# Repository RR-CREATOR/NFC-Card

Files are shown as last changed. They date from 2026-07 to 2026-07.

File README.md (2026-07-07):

# RRcard

RRcard is my NFC business card / hacker card. It uses an NT3H2111 NFC chip with a PCB antenna, so tapping it with a phone can open my links without needing a QR code or typing anything manually.

I made this because normal business cards are kinda boring, and I wanted something that felt more like a PCB project than paper with text on it. I also wanted an excuse to KiCad, fight NFC antenna math, and see if I could get a tiny board fab-ready.

## Pictures

### Full 3D model

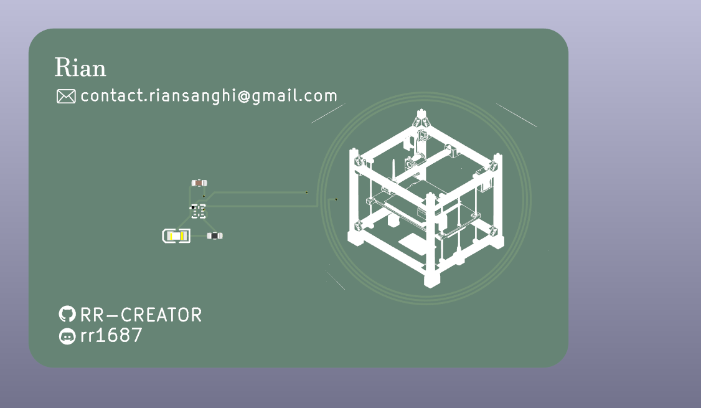
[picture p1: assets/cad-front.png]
Full 3D model front


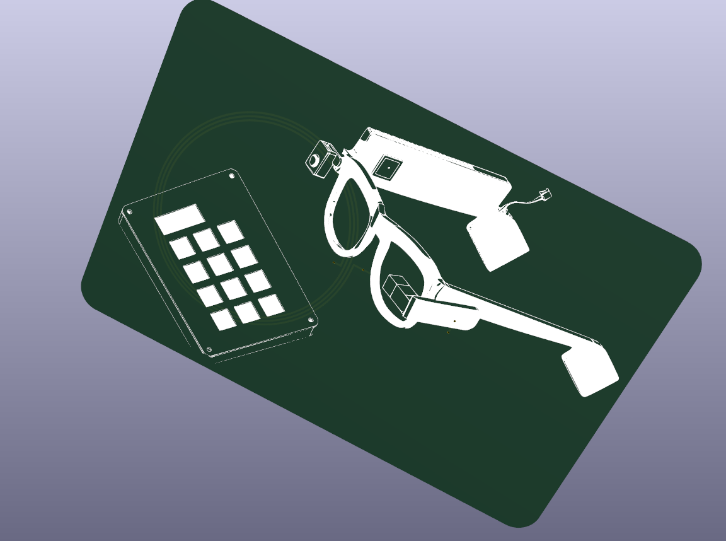
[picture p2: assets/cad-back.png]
Full 3D model back


### PCB

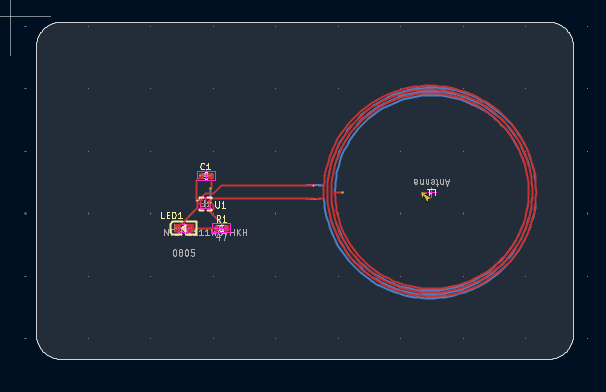
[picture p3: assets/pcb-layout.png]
PCB layout


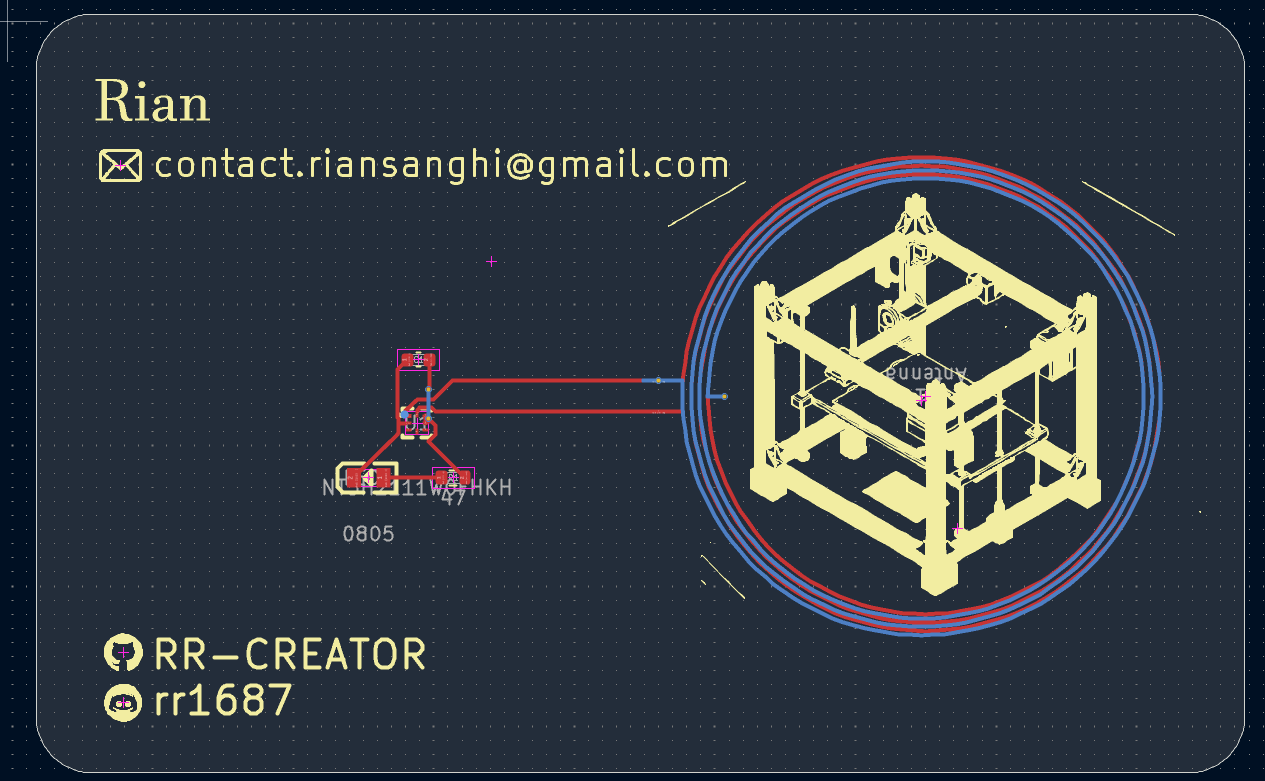
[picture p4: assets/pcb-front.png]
PCB front


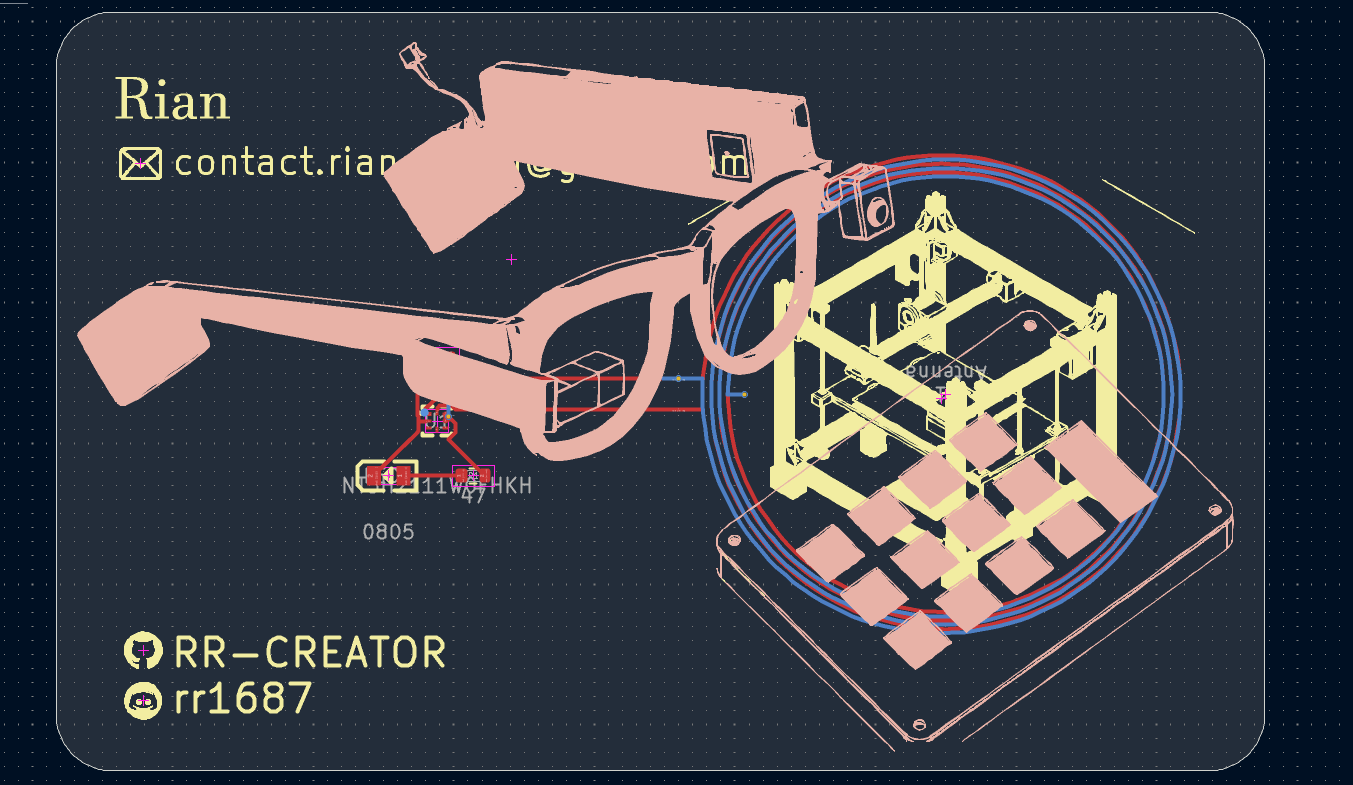
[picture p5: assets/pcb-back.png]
PCB back


### Schematic

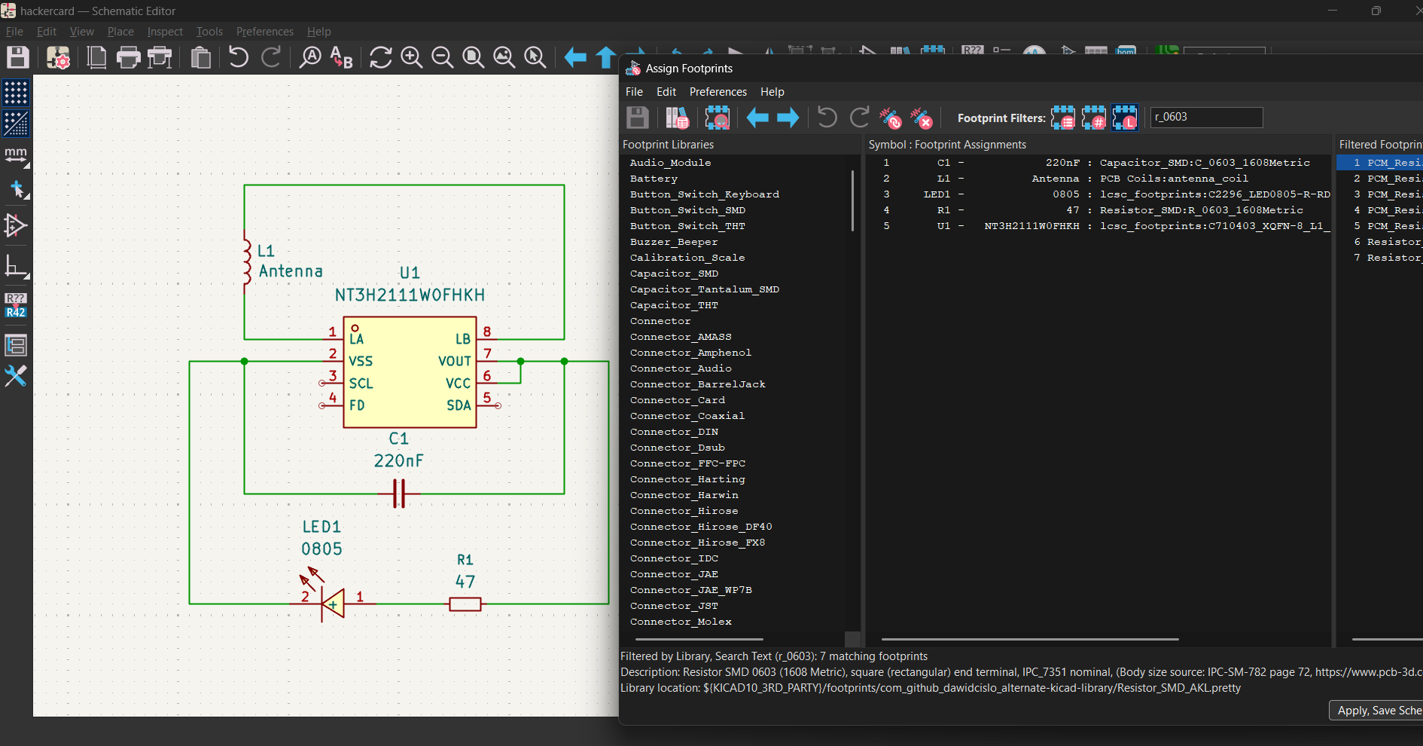
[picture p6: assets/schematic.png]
Schematic


## PCB design files

The KiCad files are in [`PCB design files`](PCB%20design%20files).

The JLCPCB production files are in [`PCB design files/jlcpcb/production_files`](PCB%20design%20files/jlcpcb/production_files).

## JLCPCB order cost

The final JLCPCB cart total came out to **$21.78 USD**.

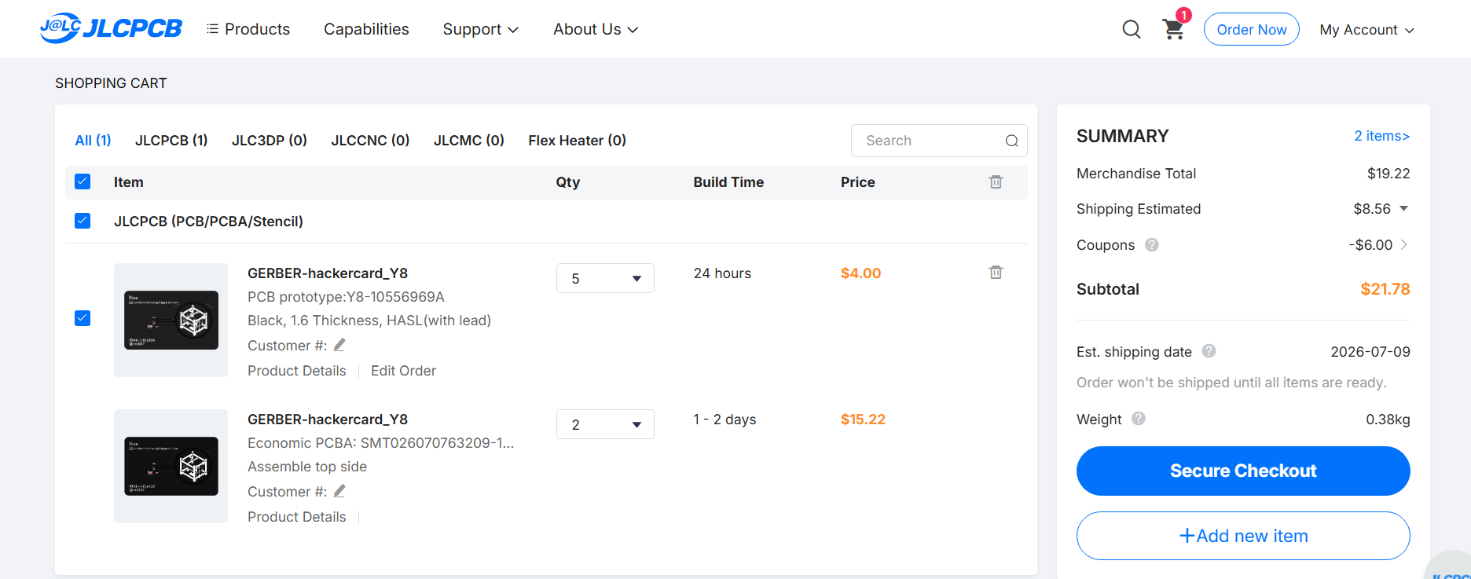
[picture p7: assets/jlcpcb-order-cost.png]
JLCPCB cart total


## BOM

| Comment | Designator | Footprint | LCSC Part # | Quantity |
| --- | --- | --- | --- | ---: |
| 805 | LED1 | C2296_LED0805-R-RD | C84256 | 1 |
| 220nF | C1 | C_0603_1608Metric | C21120 | 1 |
| 47 | R1 | R_0603_1608Metric | C23182 | 1 |
| NT3H2111W0FHKH | U1 | C710403_XQFN-8_L1_6-W1_6-P0_50-BL_NT3H2111W0FHKH | C710403 | 1 |

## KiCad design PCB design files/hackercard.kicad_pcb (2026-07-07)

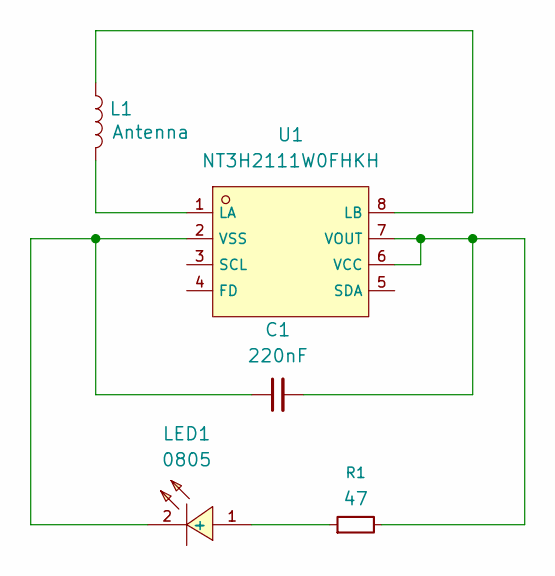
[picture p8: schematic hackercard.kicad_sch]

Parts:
C1: 220nF; C_0603_1608Metric; JLC Part # C21120
L1: Antenna; antenna_coil
LED1: 0805; C2296_LED0805-R-RD; JLC Part # C84256
R1: 47; R_0603_1608Metric; JLC Part # C23182
U1: NT3H2111W0FHKH; C710403_XQFN-8_L1_6-W1_6-P0_50-BL_NT3H2111W0FHKH; JLC Part # C710403

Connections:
unnamed: LED1.1 (+), R1.1
unnamed: C1.1, LED1.2 (-), U1.2 (VSS)
unnamed: L1.2, U1.1 (LA)
unnamed: L1.1, U1.8 (LB)
unnamed: C1.2, R1.2, U1.6 (VCC), U1.7 (VOUT)

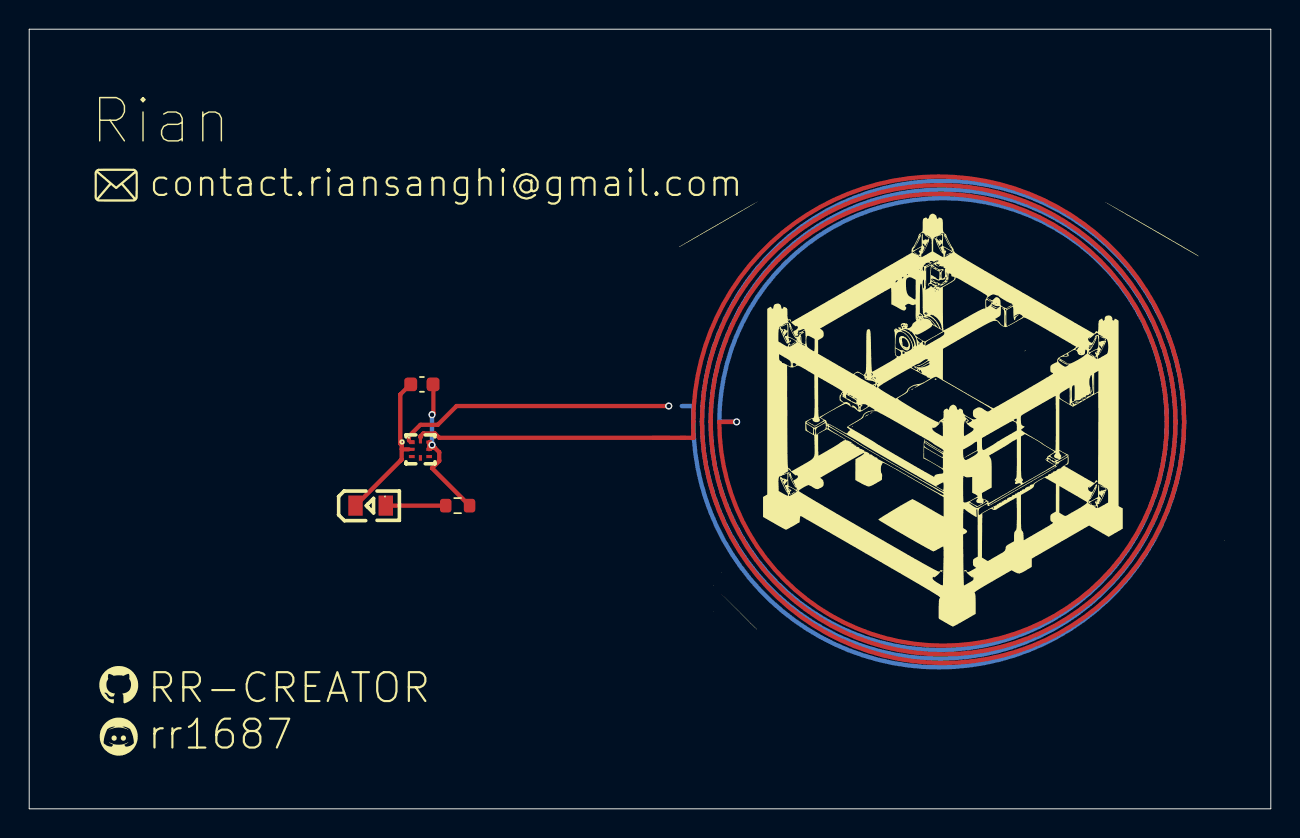
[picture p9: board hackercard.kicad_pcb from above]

Board: 2 copper layers, 86.0 x 54.0 mm, 5 parts (0 on the bottom side), 5 nets.

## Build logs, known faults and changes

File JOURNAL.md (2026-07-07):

---
title: "RRcard"
author: "rrop/rr-creator"
description: "A generic NFC business/hacker card"
created_at: "2026-07-07"
---

# 7th July: Entire PCB speedrun

Finished inserting and importing all components into KiCad, spent like 15 mins



oook, so guys, im making this on kicad :)

and sooo, like the super smart person that I am, I spent 1 hour trying to figure out how to make a custom coil through python in kicad :)

and it didn't work

So I did some redditing and found there is a plugin that generates a coil to your exact specs

and now I wanna kill myself :)

😭 Now doing some math

```text
Fuck me, this took 2 hrs to figure out
=== Target inductance from chip capacitance ===
Chip: NT3H2111, C_chip = 50 pF
Target frequency: f = 13.56 MHz

L_target = 1 / ((2*pi*f)^2 * C_chip)

(2*pi*13.56e6) = 8.5208e7 rad/s
(8.5208e7)^2   = 7.2604e15
7.2604e15 * 50e-12 = 3.6302e5
L_target = 1 / 3.6302e5 = 2.7547e-6 H = 2.75 uH

=== Coil geometry ===
Formula: L = K1 * mu0 * n^2 * d_avg / (1 + K2*rho)
K1 = 2.25, K2 = 3.55  (circular spiral constants)
mu0 = 4*pi*1e-7 = 1.25664e-6 H/m

Chosen geometry:
  d_out        = 34 mm  = 0.034 m
  trace width  = 0.3 mm
  trace space  = 0.3 mm
  pitch        = width + space = 0.6 mm/turn
  turns/layer  = 3
  layers       = 2
  n (series)   = 3*2 = 6

Per-layer inner diameter:
  radial_buildup = turns_per_layer * pitch = 3 * 0.6mm = 1.8mm
  d_in = d_out - 2*radial_buildup = 34 - 2(1.8) = 30.4 mm = 0.0304 m

Average diameter and fill ratio:
  d_avg = (d_out + d_in)/2 = (34+30.4)/2 = 32.2 mm = 0.0322 m
  rho   = (d_out - d_in)/(d_out + d_in) = (34-30.4)/(34+30.4) = 3.6/64.4 = 0.05590

Denominator:
  1 + K2*rho = 1 + 3.55*0.05590 = 1 + 0.19845 = 1.19845

Numerator:
  K1 * mu0 * n^2 * d_avg
  = 2.25 * 1.25664e-6 * 36 * 0.0322
  = 2.8274e-6 * 36 = 1.01786e-4
  = 1.01786e-4 * 0.0322 = 3.2775e-6

L = 3.2775e-6 / 1.19845 = 2.7348e-6 H = 2.7348 uH

Result: 2.735 uH (calculated) vs 2.755 uH (target) -- 0.7% delta, within
formula's own uncertainty band.

=== Error propagation ===
Assume formula error range: +/-10-20%

L_low  = 2.75uH * 0.85 = 2.3375 uH
L_high = 2.75uH * 1.15 = 3.1625 uH

f_res = 1 / (2*pi*sqrt(L * C_chip))

At L_low  = 2.3375uH: f_res = 1/(2*pi*sqrt(2.3375e-6 * 50e-12))
  sqrt(2.3375e-6*50e-12) = sqrt(1.16875e-16) = 1.0811e-8
  f_res = 1/(2*pi*1.0811e-8) = 1/6.7925e-8 = 14.72 MHz

At L_high = 3.1625uH: f_res = 1/(2*pi*sqrt(3.1625e-6 * 50e-12))
  sqrt(3.1625e-6*50e-12) = sqrt(1.58125e-16) = 1.2575e-8
  f_res = 1/(2*pi*1.2575e-8) = 1/7.9013e-8 = 12.66 MHz

Result: actual resonance likely falls in 12.7-14.7 MHz range against a
13.56 MHz target.
```

Another 15 mins and schematic and footprint assignment done :)



done routing in 15mins



spent 45mins and finished front and back silkscreen





**Total time spent: 4.5 hours**

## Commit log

2026-07-07 Add PCB design files
    [NFC Personal Card.kicad_pcb, NFC Personal Card.kicad_sch, hackercard.kicad_pcb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]
2026-07-07 Fix PCB design files path
    [NFC Personal Card.kicad_pcb, NFC Personal Card.kicad_sch, hackercard.kicad_pcb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]
2026-07-07 Add production files and README
    [BOM-hackercard.csv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]
2026-07-07 Add root production files
    [BOM-hackercard.csv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]
2026-07-07 Replace C2295 with C84256
    [BOM-hackercard.csv, hackercard.kicad_pcb, hackercard.kicad_sch]
